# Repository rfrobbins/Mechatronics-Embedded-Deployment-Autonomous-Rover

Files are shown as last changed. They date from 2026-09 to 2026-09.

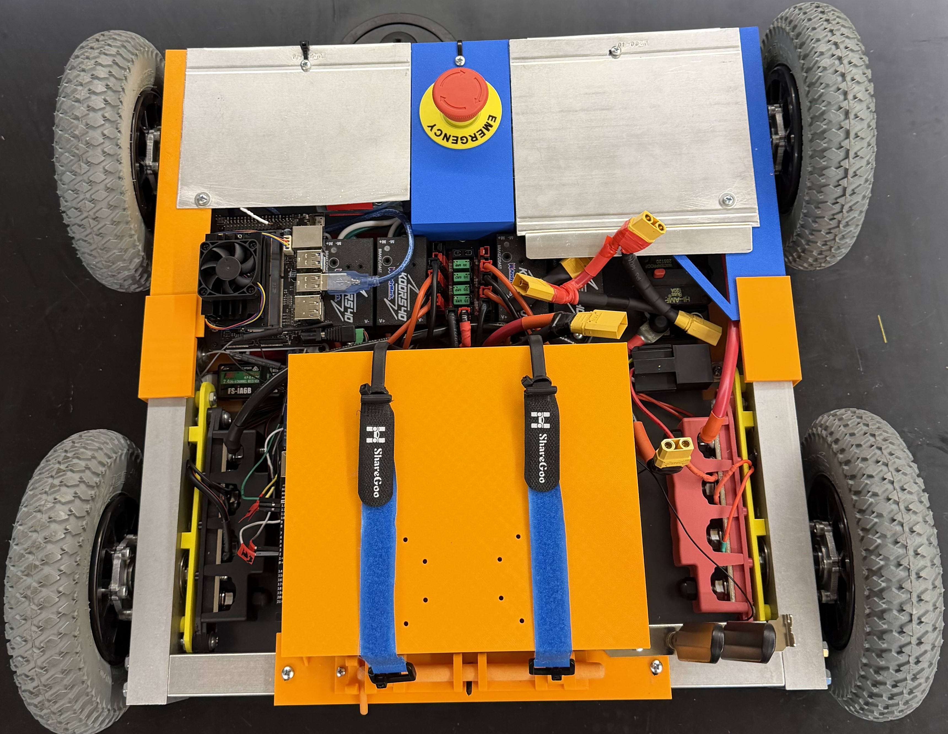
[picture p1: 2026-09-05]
images/RoverAbove.jpeg

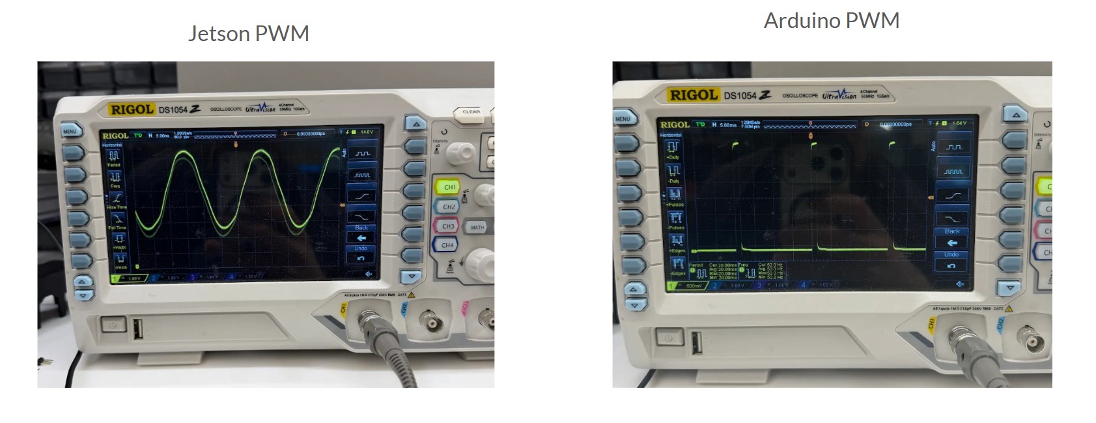
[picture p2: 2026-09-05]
images/pwm_comparison.jpg

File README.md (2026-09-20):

# Autonomous Rover Testbed

A four-wheel skid-steer rover built as a modular platform for manual control and future autonomous-control development.

The rover uses an **NVIDIA Jetson Nano** for high-level control and an **Arduino Mega** for low-level motor control.

## Quick Start

> **Safety:** Keep the rover disarmed while setting up. Make sure the physical E-stop is released/reset before operation, and keep it accessible whenever the drivetrain is powered.

1. Check that the Arduino USB cable is securely connected to the Jetson.
2. Check that the Jetson barrel-jack power connection is secure.
3. Make sure all switches on the top of the FlySky remote are in the fully **UP** position.
4. Connect the XT90 battery connector.
5. Confirm power/status lights are visible on the Jetson Nano, Arduino Mega, motor controllers, and FlySky receiver.
6. Turn on the remote by pressing both power buttons at the same time. It should automatically connect to the receiver.
7. Connect a keyboard and mouse to the Jetson and a monitor to the DisplayPort.
8. Log in to the Jetson and open a terminal.
9. Start the rover control program:

```bash
sudo python3 jetsonfinal.py
```

10. Confirm that controller inputs, arm state, and speed mode are being displayed in the terminal.
11. To enable driving, move the **top-left switch on the remote downward**.
12. Select a speed with the three-position switch directly to the right.

```text
UP      = Low
MIDDLE  = Medium
DOWN    = High
```

13. Use the **right joystick** to drive the rover.

To stop normal operation, return the enable switch to the **UP** position.

For emergency shutdown, use the physical **E-stop**.

## Software

### Jetson

The main control program is:

```text
jetsonfinal.py
```

Run it with:

```bash
sudo python3 jetsonfinal.py
```

To edit it directly on the Jetson:

```bash
nano jetsonfinal.py
```

You can also SSH into the Jetson and edit the file using a preferred coding platform.

### Arduino

Arduino code should be edited and uploaded using the **Arduino IDE**.

1. Disconnect the Arduino from the Jetson.
2. Connect it to a PC with USB.
3. Open the Arduino sketch in Arduino IDE.
4. Select the correct board and serial port.
5. Upload the code.
6. Reconnect the Arduino to the Jetson.

The Arduino serial device used by the Python program must match the USB port/device assigned by the Jetson.

## Documentation

Full operating guide:

```text
docs/OPERATING_GUIDE.md
```

Software development and controller channel mapping:

```text
docs/DEVELOPMENT.md
```

## Demonstration Videos

Driving Demonstration:

https://www.youtube.com/watch?v=0dPNv8tmsvw

Emergency Stop Functionality:

https://www.youtube.com/watch?v=sDpVlpVIPuo

Additional Rover Features:

https://www.youtube.com/watch?v=tUtS9Z2b58U

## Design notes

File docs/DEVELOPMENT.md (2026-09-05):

# Software Development and Controller Channel Mapping

This document covers basic development tasks that are useful when changing the Jetson or Arduino software.

## Editing the Jetson Python Code

The main control file is:

```text
jetsonfinal.py
```

To edit it directly on the Jetson:

```bash
nano jetsonfinal.py
```

Then run the updated program with:

```bash
sudo python3 jetsonfinal.py
```

For larger changes, it may be easier to SSH into the Jetson and edit the code from a preferred development environment on another computer.

## Editing the Arduino Code

Use the **Arduino IDE** to make changes to the Arduino program.

1. Connect the Arduino Mega to a PC with USB.
2. Open the rover Arduino sketch.
3. Select the correct Arduino board.
4. Select the correct serial port.
5. Upload the code.
6. Reconnect the Arduino to the Jetson.

The USB serial device used by the Jetson can change depending on the port or connection order. The device configured in the Python program must match the Arduino's actual serial device.

## Mapping Additional Controller Switches and Buttons

The FlySky controller has additional switches and controls that can be assigned to future rover functions.

To identify which iBUS channel corresponds to a switch or button, temporarily print the decoded channel values after a valid iBUS packet is received.

For example:

```python
print(
    "CH1:", channels[0],
    "CH2:", channels[1],
    "CH3:", channels[2],
    "CH4:", channels[3],
    "CH5:", channels[4],
    "CH6:", channels[5],
    "CH7:", channels[6],
    "CH8:", channels[7],
    "CH9:", channels[8],
    "CH10:", channels[9]
)
```

> **Important:** Perform controller-channel testing with the **motors disabled** or with the rover securely lifted so the wheels cannot drive the rover.

Run the program and move only **one controller switch or control at a time**.

Example output:

```text
CH1: 1500 CH2: 1500 CH3: 1000 CH4: 1500 CH5: 1000 CH6: 1500 CH7: 1000
CH1: 1500 CH2: 1500 CH3: 1000 CH4: 1500 CH5: 1000 CH6: 1500 CH7: 2000
```

Because only `CH7` changed from `1000` to `2000`, that switch corresponds to **iBUS channel 7**.

## Python Channel Indexing

Python lists start at index zero.

Therefore:

```python
channels[0]
```

is iBUS **Channel 1**.

Likewise:

```text
iBUS Channel 1  -> channels[0]
iBUS Channel 2  -> channels[1]
iBUS Channel 3  -> channels[2]
...
iBUS Channel 10 -> channels[9]
```

Keep this offset in mind whenever adding a new switch, button, or proportional control to `jetsonfinal.py`.

## Recommended Development Workflow

When testing new functionality:

1. Keep the rover disarmed.
2. If possible, disable drivetrain power or lift the rover.
3. Print and verify the intended input channel.
4. Add the new software behavior.
5. Verify the behavior in the terminal before allowing motor commands.
6. Test at the lowest speed first.
7. Keep the E-stop accessible.

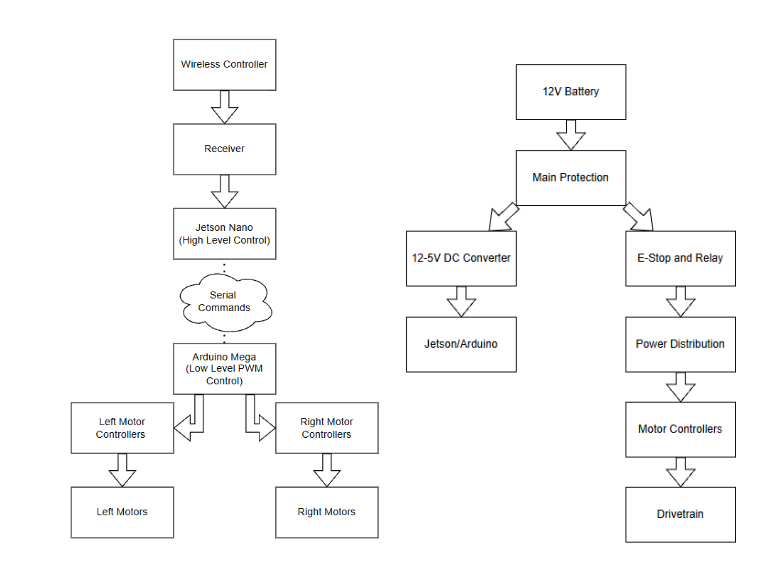
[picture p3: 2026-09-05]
images/system_architecture.png

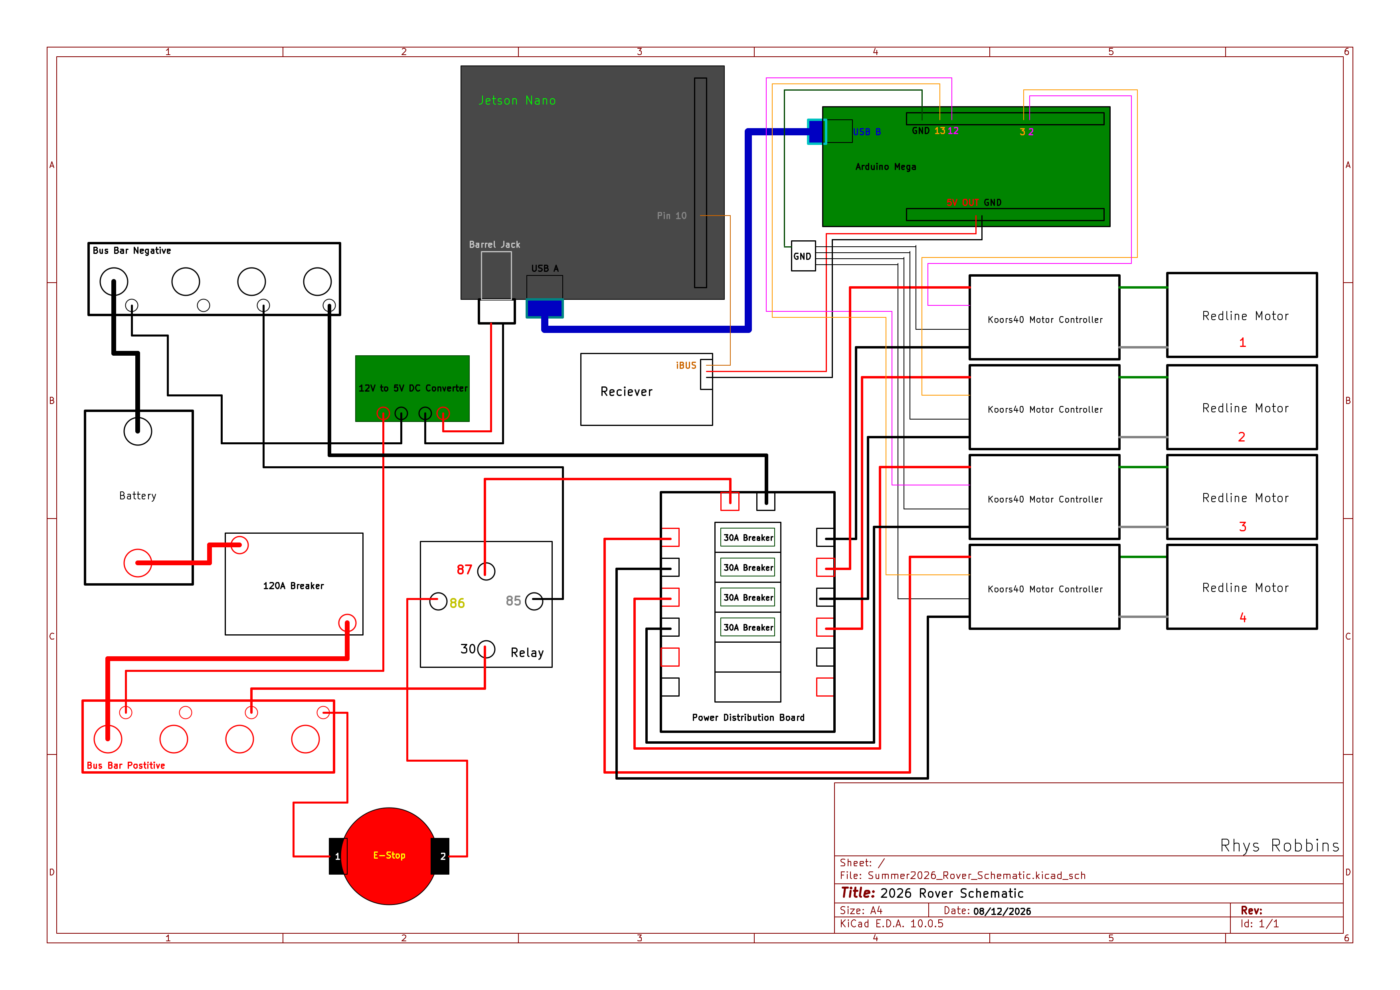
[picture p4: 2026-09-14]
schematics/RoverSchematic.png

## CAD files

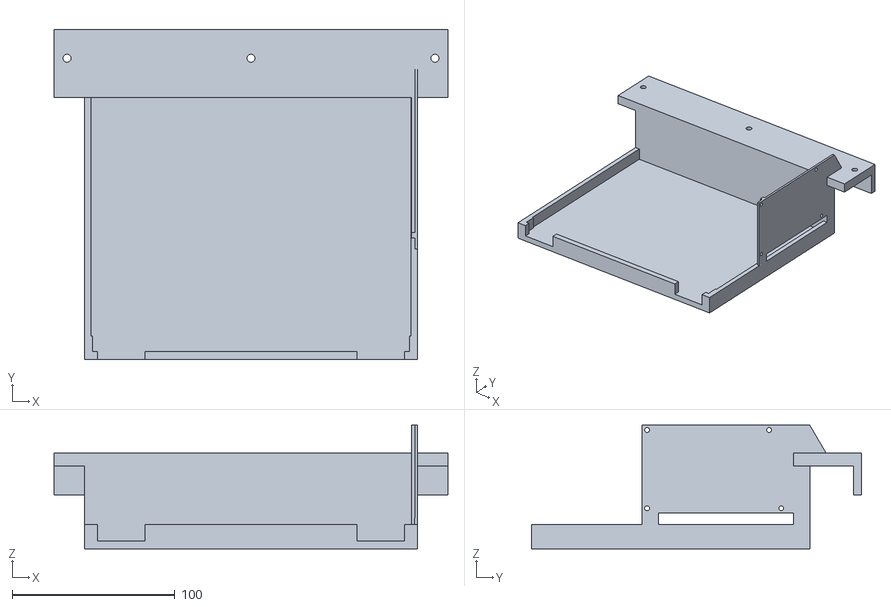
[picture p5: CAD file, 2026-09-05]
cad/Battery_Mount_V2.stl
242.2 x 202.8 x 76.1

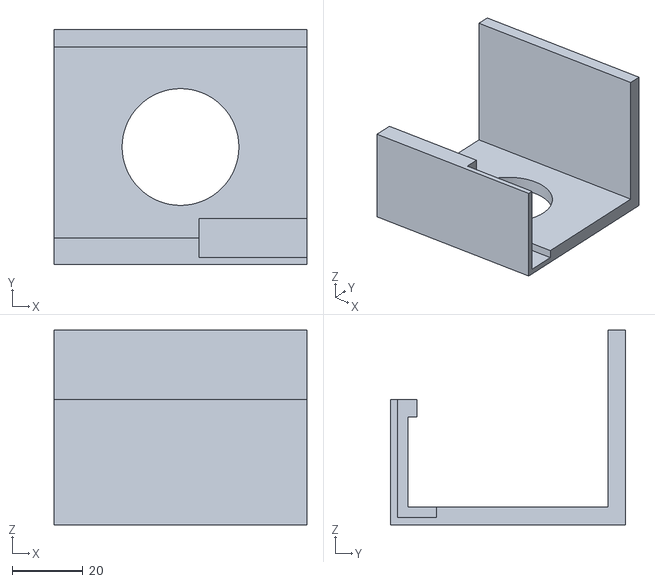
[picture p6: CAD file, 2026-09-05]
cad/Plexiglass_Support_Right.stl
71.5 x 66.5 x 55.0

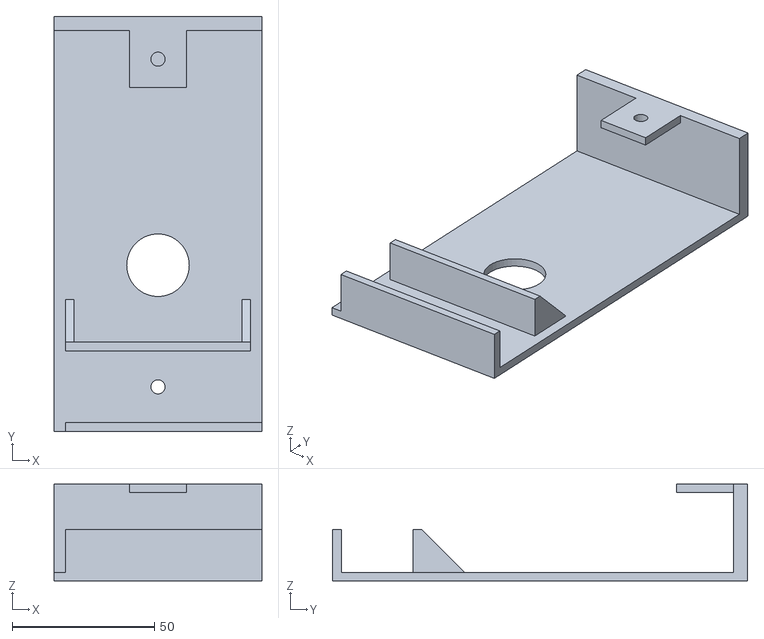
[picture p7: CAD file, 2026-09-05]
cad/ESTOP_mount.stl
73.0 x 146.0 x 34.0

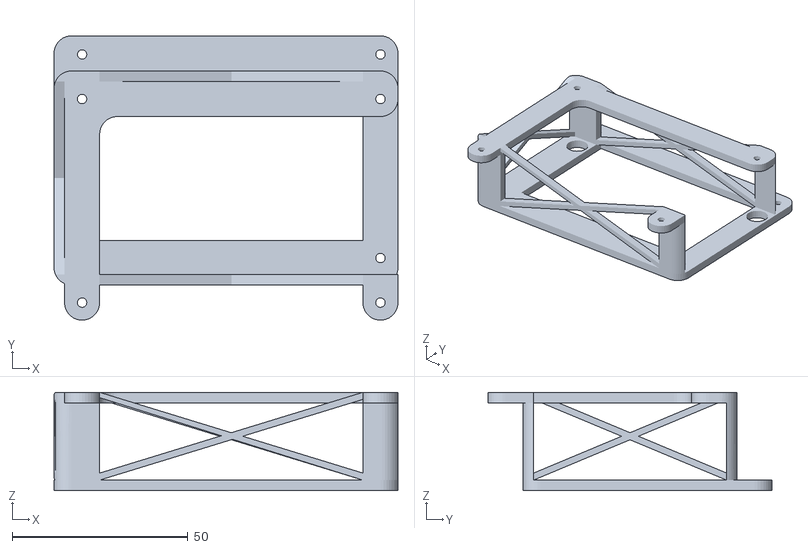
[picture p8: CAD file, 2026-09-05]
cad/Jetson_Mounting_Plate.stl
98.0 x 81.0 x 28.0

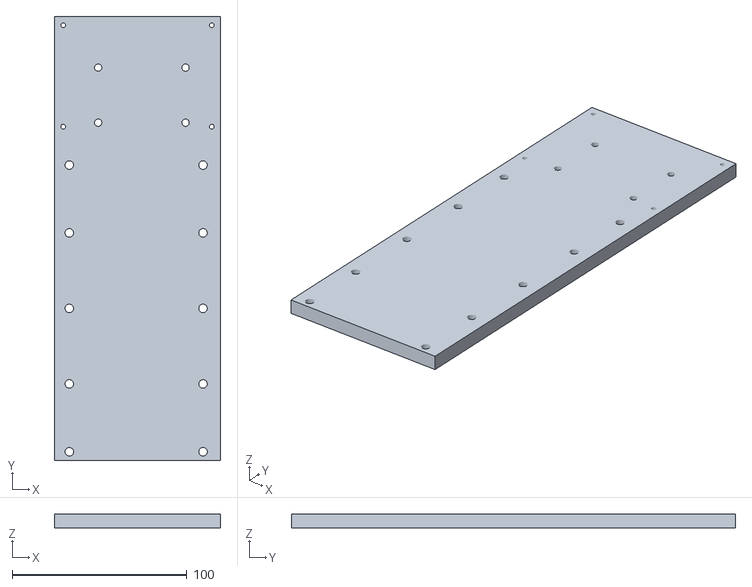
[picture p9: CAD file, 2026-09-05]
cad/PDB_MotorController_Jetson_Mounting_Plate.stl
95.0 x 254.0 x 8.00

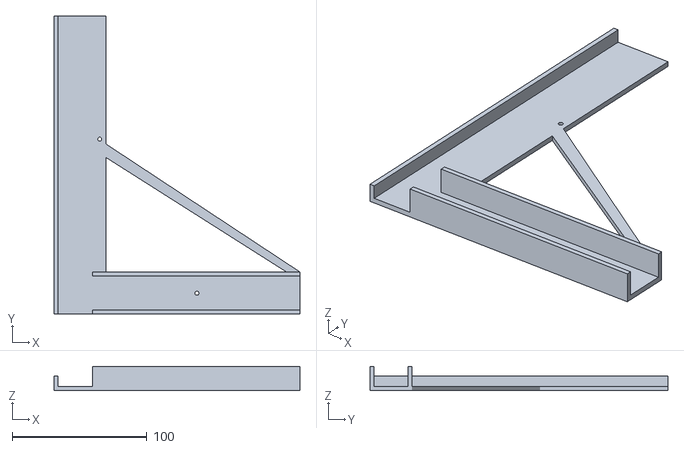
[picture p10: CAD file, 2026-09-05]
cad/Aluminium_Cover_Mount_Right.stl
182.4 x 221.2 x 18.0

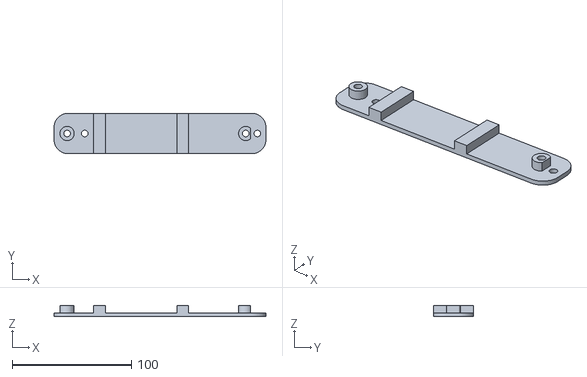
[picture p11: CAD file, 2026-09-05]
cad/Bus_Bar_Side_Mount.stl
178.0 x 34.0 x 9.20

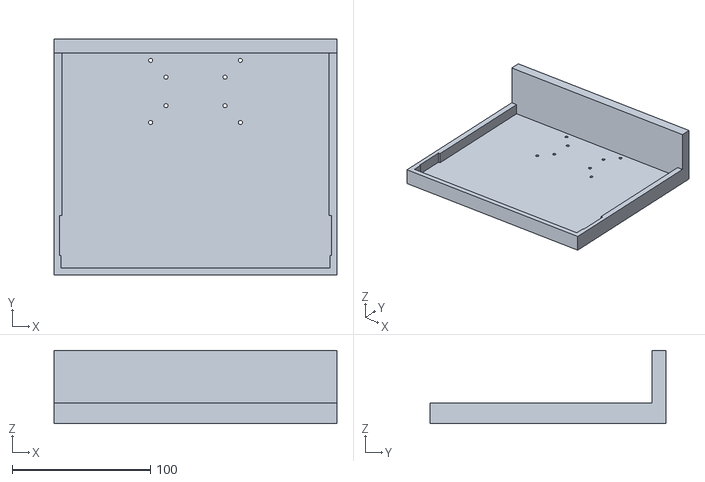
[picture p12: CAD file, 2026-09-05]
cad/Sensor_Mount.stl
205.0 x 171.0 x 53.0

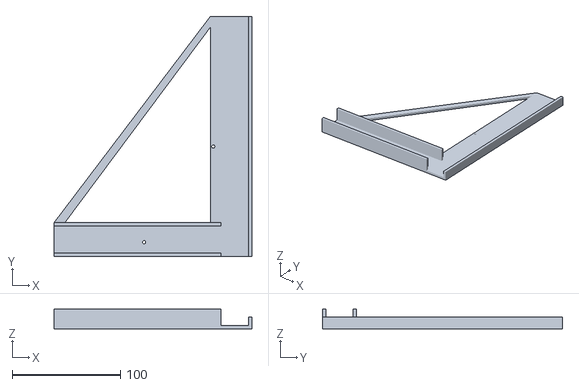
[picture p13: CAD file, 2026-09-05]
cad/Aluminium_Cover_Mount_Left.stl
182.4 x 221.2 x 18.0

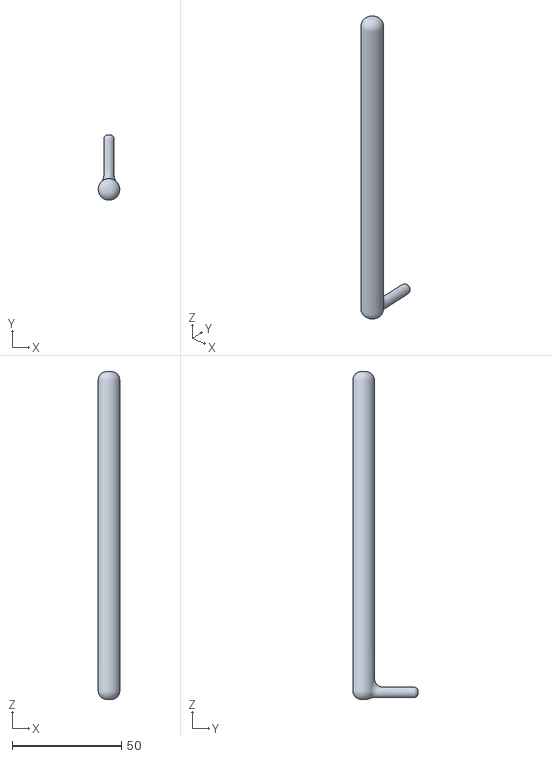
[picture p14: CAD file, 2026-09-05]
cad/barrel_bolt_latch/Bolt.stl
9.90 x 29.9 x 150.0

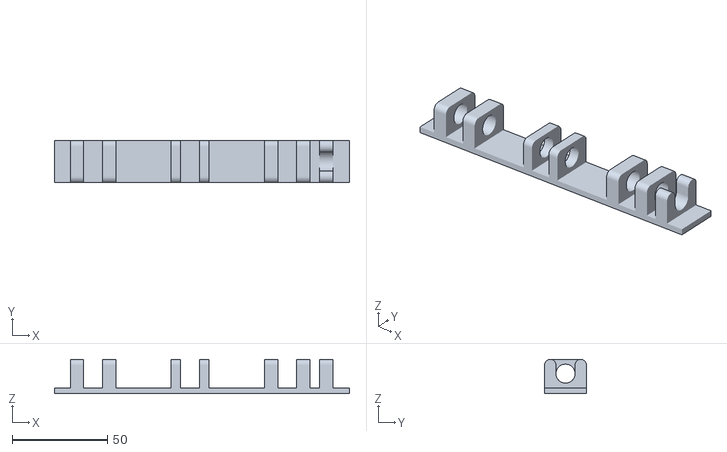
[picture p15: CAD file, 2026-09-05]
cad/barrel_bolt_latch/Sliding_Bolt_Housing.stl
155.0 x 22.0 x 18.0

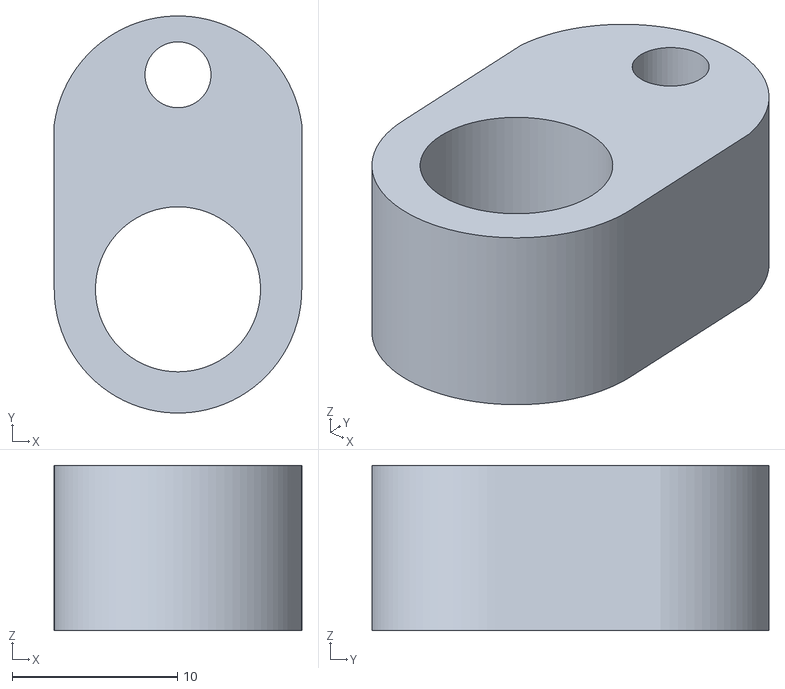
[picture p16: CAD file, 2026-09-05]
cad/barrel_bolt_latch/Locks_For_Sliding_Bolt.stl
15.0 x 24.1 x 10.0

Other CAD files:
cad/Plexiglass_Support_Left.stl

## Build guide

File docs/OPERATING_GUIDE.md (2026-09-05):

# Rover Operating Guide

This guide contains the full startup, operation, and shutdown procedure for the Autonomous Rover Testbed.

## Before Powering the Rover

1. Make sure the physical **E-stop is released/reset and not pressed**.
2. Check the Arduino USB connection to the Jetson.
3. Check that the Jetson barrel jack is fully connected.
4. Make sure all switches along the top of the remote control are in the fully **UP** position.
5. Keep the rover disarmed while completing setup.

## Power-Up Procedure

1. Plug in the **XT90 battery connector**.
2. Check for power/status lights on:
   - Jetson Nano
   - Arduino Mega
   - Motor controllers
   - FlySky receiver
3. If one of these devices does not appear to have power, stop and check the wiring before continuing.
4. Turn on the FlySky remote by pressing **both power buttons at the same time**.
5. The remote should automatically connect to the receiver.

## Jetson Setup

1. Plug a mouse and keyboard into the Jetson USB ports.
2. Connect a monitor to the Jetson DisplayPort.
3. Log in to the Jetson.
4. Open a terminal.
5. Run:

```bash
sudo python3 jetsonfinal.py
```

6. Once the program starts, use the terminal to monitor the controller inputs, enable state, speed mode, and motor commands.

## Driving the Rover

### Enable Switch

The switch at the **top-left of the remote control** is used to enable and disable rover motion.

- **Up:** Disabled
- **Down:** Enabled

Before enabling the rover:

- Make sure the steering and throttle controls are centered.
- Make sure the rover has enough clear space to move.
- Keep the E-stop accessible.

Move the enable switch downward to arm/enable driving.

The current enable state is displayed in the Jetson terminal.

### Speed Switch

The three-position switch immediately to the right of the enable switch controls the speed setting.

- **Fully up:** Low speed
- **Middle:** Medium speed
- **Fully down:** Maximum speed

The selected speed mode is displayed in the terminal.

### Manual Driving

Use the **right joystick** to control the rover manually.

The control software supports forward/reverse motion and steering through the rover's skid-steer drive system.

## Normal Stop

To stop driving normally:

1. Return the enable switch to the **UP** position.
2. Confirm in the terminal that the rover is disabled/disarmed.
3. Center the joystick.

## Emergency Stop

If immediate physical shutdown of the drivetrain is required, press the **E-stop**.

The E-stop removes drivetrain power while allowing the Jetson and Arduino control electronics to remain powered.

## Software Stop

To stop the Python program from the terminal, press:

```text
Ctrl + C
```

The program should send a neutral command before closing the serial connections.

## Power-Down Procedure

1. Move the enable switch to the **UP** position.
2. Center the joystick.
3. Stop the Python program with `Ctrl + C`.
4. Confirm the rover is no longer commanding motion.
5. Disconnect the XT90 battery connector.
6. Turn off the FlySky remote.

## Troubleshooting

### Rover software cannot connect to the Arduino

The Arduino USB device/port assigned by the Jetson matters for serial communication.

If the software cannot find the Arduino:

1. Check the USB cable.
2. Try reconnecting the Arduino.
3. Check which serial device the Jetson assigned.
4. Update the Arduino serial-port setting in `jetsonfinal.py` if necessary.
5. Alternatively, reconnect using the USB port expected by the current configuration.

### Remote does not appear connected

- Confirm the receiver has power.
- Confirm the remote was turned on by pressing both power buttons.
- Check the terminal for changing controller inputs.
- Power-cycle the remote/receiver if necessary.

### Inputs appear wrong

Do not drive the rover until the controller channel mapping has been verified.

See [DEVELOPMENT.md](DEVELOPMENT.md) for the controller-channel test procedure.

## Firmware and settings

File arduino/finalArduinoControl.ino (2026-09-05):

#include <Servo.h> 
#include <stdlib.h>
#include <string.h>

//===================================================
//Initialize & Set Parameters
//===================================================

Servo left1; 
Servo left2; 
Servo right3; 
Servo right4; 

//Arduino physical output pins 
const byte LEFT_M1 = 2; 
const byte LEFT_M2 = 3;
const byte RIGHT_M3 = 12;
const byte RIGHT_M4 = 13;

//Baud rate
const unsigned long BAUD = 115200; 

//PWM Nuetral us
const int NEUTRAL = 1500; 

//PWM Delta Value
const int DELTA = 500; 

//SOFTWARE POWER LIMITER (Value is percentage of full power)
const int POWER_LIMIT = 40;

//Min and max power calculated based on power limit percentage. 
const int MIN = NEUTRAL - (DELTA * POWER_LIMIT / 100); 
const int MAX = NEUTRAL + (DELTA * POWER_LIMIT / 100);

//Failsafe time
const unsigned long FAILSAFE = 500; 

char buffer[32]; 
byte bufferIndex = 0; 

unsigned long lastCommandTime = 0; 

//===================================================
//Power Inversion 
//Motors are set up so each gearbox has one inverted. 
//===================================================
const bool INVERT_LEFT_M1  = false;
const bool INVERT_LEFT_M2  = true;
const bool INVERT_RIGHT_M3 = true;
const bool INVERT_RIGHT_M4 = true;

int invertPulse(int pulse, bool invert){
  if(!invert){
    return pulse; 
  }
  // Min becomes max, and max becomes min. 
  return (2 * NEUTRAL) - pulse;
}

//===================================================
//Set PWM For Left and Right Gearboxes
//===================================================

void setMotors(int leftPWM, int rightPWM){
  //constrain to min and max us
  leftPWM = constrain(leftPWM, MIN, MAX); 
  rightPWM = constrain(rightPWM, MIN, MAX); 

  //Write Left Motors 
  left1.writeMicroseconds(invertPulse(leftPWM, INVERT_LEFT_M1)); 
  left2.writeMicroseconds(invertPulse(leftPWM, INVERT_LEFT_M2)); 

  //Write Right Motors 
  right3.writeMicroseconds(invertPulse(rightPWM, INVERT_RIGHT_M3)); 
  right4.writeMicroseconds(invertPulse(rightPWM, INVERT_RIGHT_M4)); 
}

void neutral(){
  setMotors(NEUTRAL,NEUTRAL); 
}

//===================================================
//Process Jetson Commands 
//Excepted Format: leftPWM_us,rightPWM_us
//===================================================

void processCommand(char *command){
  //find comma address
  char *comma = strchr(command, ','); 

  if(comma == NULL){
    Serial.println("ERROR: Invalid command format.");
    return; 
  }
  *comma = '\0'; //split command at comma

  int leftPWM = atoi(command); 
  int rightPWM = atoi(comma+1); 

  //Make sure commands are within excpeted PWM us values
  if(leftPWM < 1000 || leftPWM > 2000 || rightPWM < 1000 || rightPWM > 2000){
     Serial.println("ERROR: Invalid command.");
     return; 
  }

  setMotors(leftPWM, rightPWM); 

  lastCommandTime = millis(); 
}

//===================================================
//Setup
//===================================================

void setup(){
  
  Serial.begin(BAUD); 

  left1.attach(LEFT_M1); 
  left2.attach(LEFT_M2); 
  right3.attach(RIGHT_M3); 
  right4.attach(RIGHT_M4);
  
  neutral(); //send neutral command on startup

  lastCommandTime = millis(); 

  Serial.println("ARDUINO READY");
}

//===================================================
//Read Jetson Commands
//===================================================

void loop(){
  while(Serial.available()> 0){
    char jetsonCommand = Serial.read(); 

    if(jetsonCommand == '\n'){ //Newline indicates the end of a command
      buffer[bufferIndex] = '\0'; //Add a newline to the array to make it a readable string 

      if(bufferIndex > 0){ 
        processCommand(buffer); 
      }
      bufferIndex = 0; //erase command from buffer
    }
    else if(jetsonCommand != '\r'){
      if(bufferIndex < sizeof(buffer)-1){
        buffer[bufferIndex] = jetsonCommand; 
        bufferIndex++; 
      }
      else{ //oversized command 
        bufferIndex = 0; 
        Serial.println("ERROR: Command too long.");
      }
    }
  }
  //Failsafe 
  if(millis() - lastCommandTime > FAILSAFE){
  neutral();
  }
}

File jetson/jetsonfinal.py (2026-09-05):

import time
import serial

#==================================================
# CONFIGURATION
#==================================================

# Communication
ARDUINO_PORT = "/dev/ttyACM0"
BAUD = 115200

IBUS_PORT = "/dev/ttyTHS1"
IBUS_BAUD = 115200

SEND_INTERVAL = 0.05    # Every 50 ms
FAILSAFE = 0.25         # 250 ms

# PWM Settings
NEUTRAL = 1500
MAX_DELTA = 100

# Controller
TURN_CHANNEL = 0
THROTTLE_CHANNEL = 1

INVERT_TURN = False
INVERT_THROTTLE = True

# ARM switch
ARM_CHANNEL = 6

ARM_THRESHOLD = 1700
ARM_STICK_DEADZONE = 0.10

# Speed switch
# Physical controller channel 6 = Python channel index 5
SPEED_CHANNEL = 5

# Speed multipliers
LOW_SPEED = 0.40
MEDIUM_SPEED = 0.70
HIGH_SPEED = 1.00

# 3-position switch thresholds
SPEED_LOW_THRESHOLD = 1250
SPEED_HIGH_THRESHOLD = 1750

# iBUS
iBUS_MIN = 1000
iBUS_MAX = 2000
iBUS_MID = 1500
DEADZONE = 0.05


#==================================================
# iBUS DECODING
#==================================================

def read_ibus(ser):
    """
    Reads packets coming from iBUS controller and 
    validates the packet.

    Returns a list of channel values if valid.
    Otherwise returns None.
    """

    while True:

        # First byte of iBUS packet should be 0x20
        first = ser.read(1)

        if not first:
            return None

        if first[0] != 0x20:
            continue

        # Second byte should be 0x40
        second = ser.read(1)

        if not second:
            return None

        if second[0] != 0x40:
            continue

        # Remaining 30 bytes of 32-byte packet
        rest = ser.read(30)

        if len(rest) != 30:
            return None

        packet = first + second + rest

        #-------------------------------------------
        # Checksum
        #-------------------------------------------

        sender_checksum = (
            packet[30] |
            (packet[31] << 8)
        )

        calculated_checksum = (
            0xFFFF - sum(packet[:30])
        ) & 0xFFFF 

        if sender_checksum != calculated_checksum:
            continue

        #-------------------------------------------
        # Decode Channels
        #-------------------------------------------

        channels = []

        # 14 channels, 2 bytes each
        for i in range(14):

            low_byte = packet[2 + (i * 2)]
            high_byte = packet[3 + (i * 2)]

            value = (
                low_byte |
                (high_byte << 8)
            )

            channels.append(value)

        return channels


#==================================================
# JOYSTICK NORMALIZATION
#==================================================

def normalize_channel(value):

    value = max(
        iBUS_MIN,
        min(iBUS_MAX, value)
    )

    normalized = (
        (value - iBUS_MID) /
        float(iBUS_MAX - iBUS_MID)
    )

    normalized = max(
        -1.0,
        min(1.0, normalized)
    )

    # Deadzone
    if abs(normalized) < DEADZONE:
        normalized = 0.0

    return normalized


#==================================================
# SPEED CONTROL
#==================================================

def get_speed_mode(value):

    # Low switch position
    if value < SPEED_LOW_THRESHOLD:
        return LOW_SPEED, "LOW"

    # Middle switch position
    elif value < SPEED_HIGH_THRESHOLD:
        return MEDIUM_SPEED, "MEDIUM"

    # High switch position
    else:
        return HIGH_SPEED, "HIGH"


#==================================================
# DRIVE CHARACTERISTICS
#==================================================

def drive_mix(throttle, turn):

    # Inversion
    if INVERT_THROTTLE:
        throttle = -throttle

    if INVERT_TURN:
        turn = -turn

    # Differential drive mixing
    left_power = throttle + turn
    right_power = throttle - turn

    # Scale if either side exceeds 100%
    maxed = max(
        1.0,
        abs(left_power),
        abs(right_power)
    )

    left_power /= maxed
    right_power /= maxed

    return left_power, right_power


#==================================================
# SEND POWER
#==================================================

def send_power(power):

    power = max(
        -1.0,
        min(1.0, power)
    )

    return int(
        round(
            NEUTRAL + (power * MAX_DELTA)
        )
    )


#==================================================
# SERIAL
#==================================================

def send_command(ser, left_power, right_power):

    left_pwm = send_power(left_power)
    right_pwm = send_power(right_power)

    command = "{},{}\n".format(
        left_pwm,
        right_pwm
    )

    try:

        ser.write(command.encode("ascii"))

    except serial.SerialTimeoutException:

        print("ERROR: Arduino serial write timeout.")
        return None, None

    except serial.SerialException as error:

        print("ERROR: Arduino serial error: {}".format(error))
        return None, None

    return left_pwm, right_pwm


def send_neutral(ser):

    try:

        ser.write(b"1500,1500\n")
        return True

    except serial.SerialTimeoutException:

        print("ERROR: Neutral command write timeout.")
        return False

    except serial.SerialException as error:

        print("ERROR sending neutral:", error)
        return False


#==================================================
# MAIN
#==================================================
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

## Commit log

2026-09-05 Current code for jetsonfinal.py
    Runs on Jetson nano as the main control program for the rover.
2026-09-05 Current Arduino code for PWM generation and jetson communication
2026-09-05 Add cad directory with initial file
2026-09-05 Add new file to schematics
